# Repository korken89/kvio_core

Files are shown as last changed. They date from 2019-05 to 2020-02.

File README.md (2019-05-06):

# KVision Core - Visual Inertial Core

KVision core is an FPGA based Visual Inertial Odometry accelerator.

More info to come.

---

## Contributors

List of contributors in alphabetical order:

* Emil Fresk ([@korken89](https://github.com/korken89))

---

## License

The hardware is OSHW using the Cern-OHL license.

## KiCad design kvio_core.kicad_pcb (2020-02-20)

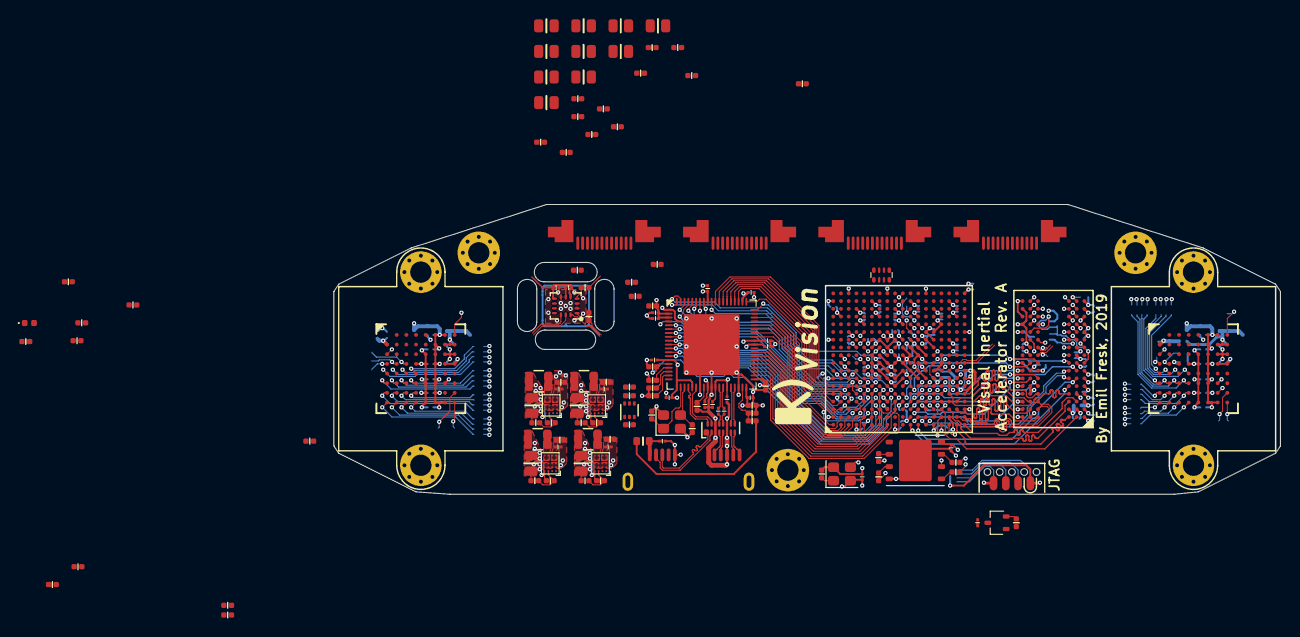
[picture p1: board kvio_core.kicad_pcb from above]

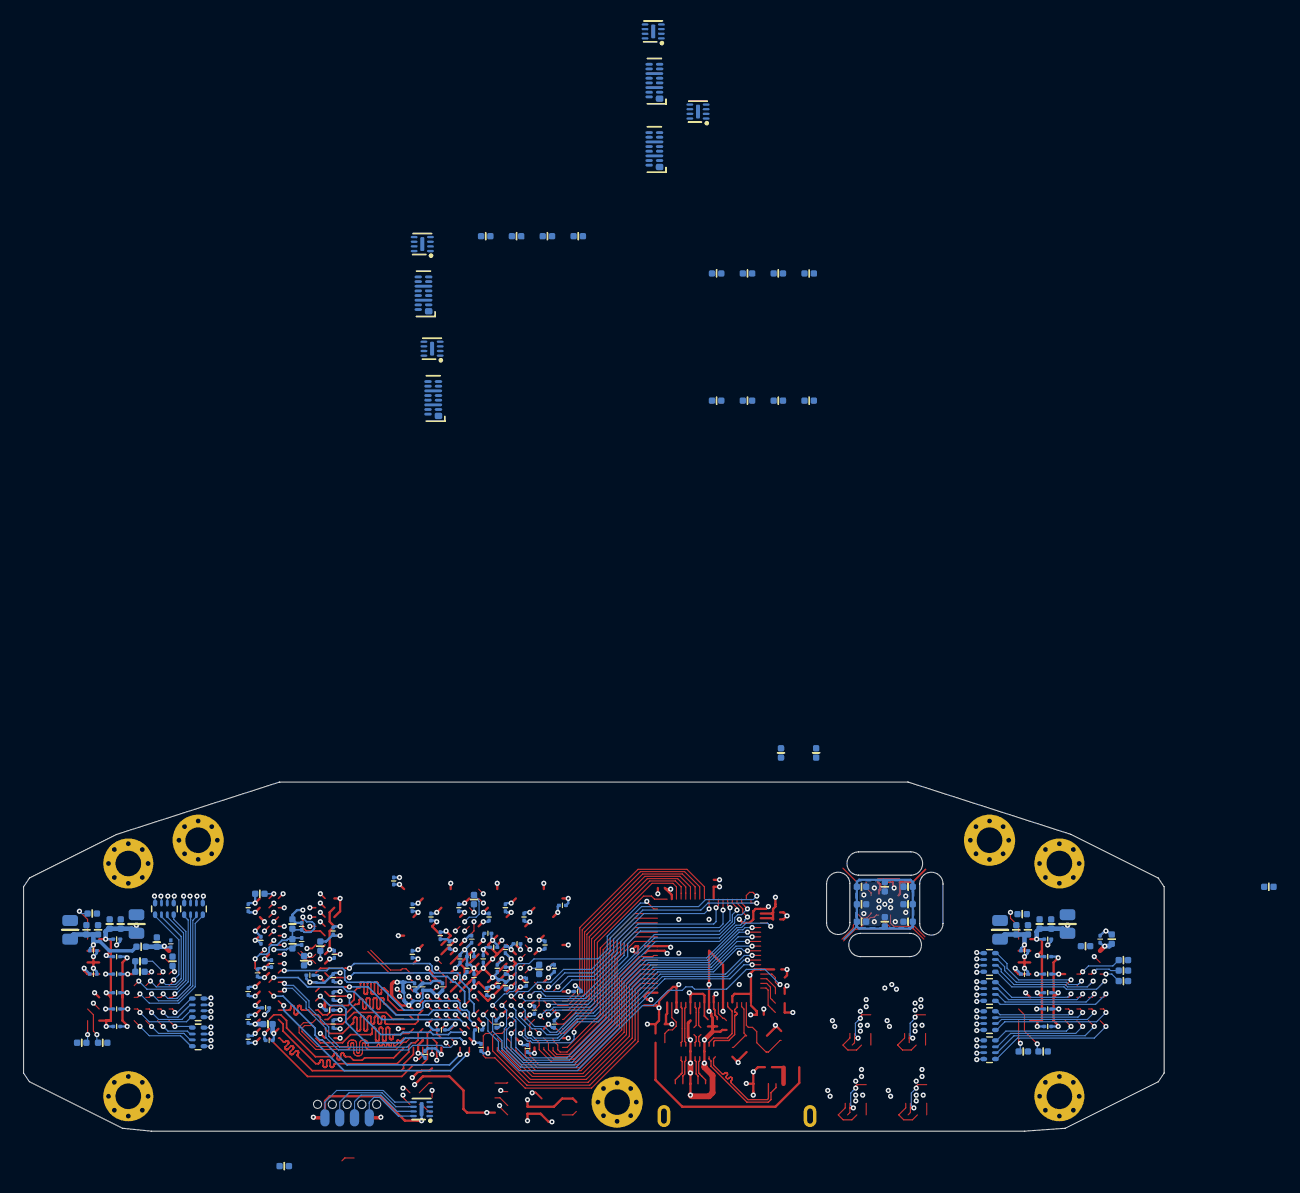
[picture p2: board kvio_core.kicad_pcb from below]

Board: 6 copper layers, 98.0 x 30.0 mm, 287 parts (154 on the bottom side), 316 nets.

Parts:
C101, C215, C216, C220, C221, C223, C224, C226, C227, C229, C230, C231, C232, C233, C234, C235, C236, C237, C240, C241, C243, C244, C245, C248, C249, C251, C252, C253, C254, C255, C261, C262, C263, C264, C265, C266, C267, C268, C269, C270, C272, C275, C278, C281, C284, C285, C301, C302, C1105, C1106, C1110, C1111, C1112, C1113, C1114, C1115, C1116, C1201, C1202, C1204, C1206, C1207, C1208, C1209, C1210, C1211, C1212, C1213, C1214, C1215, C1216, C1217, C1218, C1219, C1220, C1221, C1222, C1301, C1302, C1303, C1306, C1308, C1309, C1310, C1313, C1314, C1315, C1316, C1317, C1318, C1320, C1321, C1405, C1406, C1410, C1411, C1412, C1413, C1414, C1415, C1416: 0.1u; C_0201
C201, C202, C203, C204, C207, C208, C209, C214, C238, C239, C273, C276, C279, C282, C1101, C1104, C1401, C1404: 47u; C_0805
C205, C206, C210, C211, C212, C213, C217, C218, C219, C225, C228, C246, C247, C401, C801, C901, C1001, C1102, C1103, C1107, C1108, C1109, C1203, C1205, C1305, C1307, C1319, C1402, C1403, C1407, C1408, C1409: 4.7u; C_0402
C271, C274, C277, C280: 10u; C_0402
C1311, C1312: 18p; C_0402
D301: GREEN; LED_0402_1005Metric
FB201, FB401, FB801, FB901, FB1001, FB1101, FB1201, FB1401: Ferrite_Bead_Small; R_0402
FB1301: BLM18KG102SH1D; R_0603
H101, H102, H103: MountingHole_Pad; MountingHole_2.2mm_M2_Pad_Via
J401, J801, J901, J1001: 12-pin_FFC_(SFV12R); SFV12R
J1301: USB3_B_Micro; AMPHENOL-GSB343K33HR
L201, L202, L203, L204: 0.47uH; L_2025Metric
LH1101, LH1401: lens_holder; m12_20mm
Q1201: NTZD3155C; SOT-563
R101, R1101, R1102, R1103, R1104, R1302, R1303, R1306, R1401, R1402, R1403, R1404: 10k; R_0402
R201, R202, R203, R204, R205, R206, R207, R208: 0; R_0402
R301, R304, R311, R312, R313, R314, R401, R403, R801, R802, R901, R902, R1001, R1002, R1204, R1206, R1213, R1214, R1215, R1216, R1217: 100; R_0402
R302, R303, R1304, R1305: 470; R_0402
R307, R315, R316, R1205, R1207, R1208, R1210, R1307: 4.7k; R_0402
R308, R310, R1201, R1202: 1k; R_0402
R701, R702, R1105, R1106, R1301: 1.6k; R_0402
R1203: 240; R_0402
R1209, R1211, R1212, R1218, R1219, R1220, R1221, R1222: 180; R_0402
RN101, RN1101, RN1102, RN1103, RN1104, RN1401, RN1402, RN1403, RN1404: 22; R_Array_Convex_4x0402
U101: xc7a100t-csg324; CSG324_Artix7_100T
U102: 100 MHz; Crystal_SMD_2520-4Pin_2.5x2.0mm
U201, U202, U203, U204: FAN53541; WLCSP-20_1.96x1.56mm_Layout4x5_P0.4mm
U301: MX25L6433F; WSON-8-1EP_6x5mm_P1.27mm_EP3.4x4.3mm
U302: MAX809; SOT-323
U303, U402, U801, U901, U1001: IP4254CZ8-4-TTL; UDFN-8-1EP_1.7x1.35mm_P0.4mm_EP0.4x1.2mm
U304: SOICbite_JTAG; SOICbiteSmall
U401, U802, U902, U1002, U1302: EMI8143; XDFN-16_1.35x3.5mm
U1101, U1401: AR0135CS
U1201: MT41J128M16JT-125:K; BGA-96_8.0x14.0mm_DDR16
U1202: ASM330LHH; LGA-14-2.5x3
U1301: FT601Q; QFN-76-1EP_9x9mm_P0.4mm_EP5.8x6.3mm
Y1301: Crystal_GND24_Small; Crystal_SMD_2520-4Pin_2.5x2.0mm

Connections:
+1V0: C209.1, C214.1, C219.1, C225.1, C231.1, C237.1, C239.1, C245.1, C253.1, C255.1, C261.1, C263.1, C266.1, C267.1, C268.1, C269.1, C270.1, C282.1, L204.2, R207.1, U101.F8, U101.F10, U101.G7, U101.G9, U101.G11, U101.H8, U101.J7, U101.J11, U101.K8, U101.L7, U101.L11, U101.M8, U101.M10, U101.N7, U101.N9, U101.N11, U204.A4
+1V5: C201.1, C205.1, C210.1, C215.1, C220.1, C226.1, C232.1, C240.1, C248.1, C279.1, L203.2, R205.1, U101.K4, U101.N3, U101.P6, U101.T2, U101.U5, U101.V8, U203.A4
+1V8: C203.1, C207.1, C212.1, C217.1, C223.1, C229.1, C235.1, C238.1, C243.1, C246.1, C247.1, C251.1, C254.1, C262.1, C264.1, C265.1, C276.1, C1101.1, C1102.1, C1103.1, C1105.1, C1106.1, C1110.1, C1111.1, C1115.1, C1116.1, C1401.1, C1402.1, C1403.1, C1405.1, C1406.1, C1410.1, C1411.1, C1415.1, C1416.1, FB201.2, L202.2, R203.1, R701.2, R702.2, R1105.2, R1106.2, U101.A17, U101.C13, U101.D16, U101.E8, U101.F12, U101.G15, U101.H12, U101.H18, U101.K12, U101.K14, U101.M12, U202.A4, U1101.A6, U1101.A7, U1101.B6, U1101.C6, U1101.D6, U1101.E6, U1101.F6, U1101.G6, U1101.H6, U1101.H7, U1401.A6, U1401.A7, U1401.B6, U1401.C6, U1401.D6, U1401.E6, U1401.F6, U1401.G6, U1401.H6, U1401.H7
+3V3: C101.1, C202.1, C204.1, C206.1, C208.1, C211.1, C213.1, C216.1, C218.1, C221.1, C224.1, C227.1, C228.1, C230.1, C233.1, C234.1, C236.1, C241.1, C244.1, C249.1, C252.1, C273.1, C284.1, C301.2, C302.2, C1305.1, C1306.1, C1308.1, C1309.1, C1313.1, C1314.1, C1316.1, C1317.1, FB1201.2, L201.2, R101.1, R201.1, R302.2, R307.1, R308.1, R315.1, R316.1, R1302.1, U101.A7, U101.B10, U101.C3, U101.D6, U101.F2, U101.G5, U101.J1, U101.L17, U101.N13, U101.P8, U101.P12, U101.P16, U101.R9, U101.T12, U101.U15, U101.V18, U102.4, U201.A4, U301.8, U302.3, U1301.14, U1301.20, U1301.24, U1301.28, U1301.38, U1301.49, U1301.59, U1301.68
/CAM0_CLK: RN101.8, U1401.C1
/CAM0_CLK_P: RN101.1, U101.F18
/CAM0_D0: RN1402.8, U101.B14
/CAM0_D1: RN1402.7, U101.B12
/CAM0_D2: RN1402.6, U101.B11
/CAM0_D3: RN1402.5, U101.A11
/CAM0_D4: RN1403.8, U101.F13
/CAM0_D5: RN1403.7, U101.F14
/CAM0_D6: RN1403.6, U101.D12
/CAM0_D7: RN1403.5, U101.D13
/CAM0_D8: RN1404.8, U101.B16
/CAM0_D9: RN1404.7, U101.B17
/CAM0_D10: RN1404.6, U101.A15
/CAM0_D11: RN1404.5, U101.A16
/CAM0_FLASH: RN1401.1, U101.A18
/CAM0_FV: RN1401.3, U101.A13
/CAM0_LV: RN1401.4, U101.A14
/CAM0_PIXCLK: RN1401.2, U101.D15
/CAM0_RESET: R1404.1, U101.C12, U1401.H8
/CAM0_SCLK: R702.1, U101.E16, U1401.D2
/CAM0_SDATA: R701.1, U101.E15, U1401.D3
/CAM0_TRIGGER: RN101.7, U1401.G7
/CAM0_TRIGGER_P: RN101.2, U101.B18
/CAM1_CLK: RN101.6, U1101.C1
/CAM1_CLK_P: RN101.3, U101.G18
/CAM1_D0: RN1102.8, U101.H16
/CAM1_D1: RN1102.7, U101.G16
/CAM1_D2: RN1102.6, U101.F15
/CAM1_D3: RN1102.5, U101.F16
/CAM1_D4: RN1103.8, U101.H14
/CAM1_D5: RN1103.7, U101.G14
/CAM1_D6: RN1103.6, U101.E17
/CAM1_D7: RN1103.5, U101.D17
/CAM1_D8: RN1104.8, U101.K13
/CAM1_D9: RN1104.7, U101.J13
/CAM1_D10: RN1104.6, U101.H17
/CAM1_D11: RN1104.5, U101.G17
/CAM1_FLASH: RN1101.1, U101.C17
/CAM1_FV: RN1101.3, U101.J14
/CAM1_LV: RN1101.4, U101.H15
/CAM1_PIXCLK: RN1101.2, U101.C15
/CAM1_RESET: R1101.1, U101.B13, U1101.H8
/CAM1_SCLK: R1106.1, U101.D18, U1101.D2
/CAM1_SDATA: R1105.1, U101.E18, U1101.D3
/CAM1_TRIGGER: RN101.5, U1101.G7
/CAM1_TRIGGER_P: RN101.4, U101.C16
/Camera 1/5V_CAM: C401.1, FB401.1, J401.12
/Camera 1/CLK_N: R403.2, U401.12
/Camera 1/CLK_P: R403.1, U401.13
/Camera 1/CLK_P_N: J401.5, U401.5
/Camera 1/CLK_P_P: J401.6, U401.4
/Camera 1/D1_N: R401.2, U401.9
/Camera 1/D1_P: R401.1, U401.10
/Camera 1/D1_P_N: J401.2, U401.8
/Camera 1/D1_P_P: J401.3, U401.7
/Camera 1/IO1_P: J401.8, U402.8
/Camera 1/IO2_P: J401.9, U402.7
/Camera 1/SCL_P: J401.11, U402.5
/Camera 1/SDA_P: J401.10, U402.6
/Camera 2/5V_CAM: C801.1, FB801.1, J801.12
/Camera 2/CLK_N: R802.2, U802.12
/Camera 2/CLK_P: R802.1, U802.13
/Camera 2/CLK_P_N: J801.5, U802.5
/Camera 2/CLK_P_P: J801.6, U802.4
/Camera 2/D1_N: R801.2, U802.9
/Camera 2/D1_P: R801.1, U802.10
/Camera 2/D1_P_N: J801.2, U802.8
/Camera 2/D1_P_P: J801.3, U802.7
/Camera 2/IO1_P: J801.8, U801.8
/Camera 2/IO2_P: J801.9, U801.7
/Camera 2/SCL_P: J801.11, U801.5
/Camera 2/SDA_P: J801.10, U801.6
/Camera 3/5V_CAM: C901.1, FB901.1, J901.12
/Camera 3/CLK_N: R902.2, U902.12
/Camera 3/CLK_P: R902.1, U902.13
/Camera 3/CLK_P_N: J901.5, U902.5
/Camera 3/CLK_P_P: J901.6, U902.4
/Camera 3/D1_N: R901.2, U902.9
/Camera 3/D1_P: R901.1, U902.10
/Camera 3/D1_P_N: J901.2, U902.8
/Camera 3/D1_P_P: J901.3, U902.7
/Camera 3/IO1_P: J901.8, U901.8
/Camera 3/IO2_P: J901.9, U901.7
/Camera 3/SCL_P: J901.11, U901.5
/Camera 3/SDA_P: J901.10, U901.6
/Camera 4/5V_CAM: C1001.1, FB1001.1, J1001.12
/Camera 4/CLK_N: R1002.2, U1002.12
/Camera 4/CLK_P: R1002.1, U1002.13
/Camera 4/CLK_P_N: J1001.5, U1002.5
/Camera 4/CLK_P_P: J1001.6, U1002.4
/Camera 4/D1_N: R1001.2, U1002.9
/Camera 4/D1_P: R1001.1, U1002.10
/Camera 4/D1_P_N: J1001.2, U1002.8
/Camera 4/D1_P_P: J1001.3, U1002.7
/Camera 4/IO1_P: J1001.8, U1001.8
/Camera 4/IO2_P: J1001.9, U1001.7
/Camera 4/SCL_P: J1001.11, U1001.5
/Camera 4/SDA_P: J1001.10, U1001.6
/Config/CFG_CLK: R301.1, R304.1, U301.6
/Config/CFG_CS: R307.2, U101.L13, U301.1
/Config/CFG_D0: R311.1, U101.K17
/Config/CFG_D1: R312.1, U101.K18
/Config/CFG_D2: R313.1, R316.2, U101.L14
/Config/CFG_D3: R314.1, R315.2, U101.M14
/Config/CFG_DONE: R302.1, R303.2, U101.P10
/Config/CFG_INIT_B: R310.1, U101.P7, U101.P9
/Config/CFG_PUDC: R308.2, U101.L15
/Config/SYSTEM_RESET: R310.2, U302.2
/Config/TCK: U101.E10, U303.3
/Config/TCK_P: U303.6, U304.7
/Config/TDI: U101.E11, U303.4
/Config/TDI_P: U303.5, U304.8
/Config/TDO: U101.E13, U303.2
/Config/TDO_P: U303.7, U304.6
/Config/TMS: U101.E12, U303.1
/Config/TMS_P: U303.8, U304.5
/DDR Memory/A0: U101.U6, U1201.N3
/DDR Memory/A1: U101.R6, U1201.P7
/DDR Memory/A2: U101.V7, U1201.P3
/DDR Memory/A3: U101.V6, U1201.N2
/DDR Memory/A4: U101.T8, U1201.P8
/DDR Memory/A5: U101.P5, U1201.P2
/DDR Memory/A6: U101.R8, U1201.R8
/DDR Memory/A7: U101.N5, U1201.R2
/DDR Memory/A8: U101.R7, U1201.T8
/DDR Memory/A9: U101.N6, U1201.R3
/DDR Memory/A10: U101.P4, U1201.L7
/DDR Memory/A11: U101.N4, U1201.R7
/DDR Memory/A12: U101.U7, U1201.N7
/DDR Memory/A13: U101.M6, U1201.T3
/DDR Memory/BA0: U101.R5, U1201.M2
/DDR Memory/BA1: U101.U8, U1201.N8
/DDR Memory/BA2: U101.P3, U1201.M3
/DDR Memory/CAS_N: U101.R2, U1201.K3
/DDR Memory/CK_E: U101.T6, U1201.K9
/DDR Memory/CK_N: R1204.2, U101.V9, U1201.K7
/DDR Memory/CK_P: R1204.1, U101.U9, U1201.J7
/DDR Memory/CS_N: U101.P2, U1201.L2
/DDR Memory/DDR3_VDD: C1201.1, C1203.1, C1204.1, C1206.1, C1207.2, C1208.1, C1210.1, C1211.2, C1212.1, C1213.2, C1214.1, C1215.2, C1216.1, C1217.2, C1218.1, C1219.2, C1220.1, C1221.2, R1201.1, U1201.A1, U1201.A8, U1201.B2, U1201.C1, U1201.C9, U1201.D2, U1201.D9, U1201.E9, U1201.F1, U1201.G7, U1201.H2, U1201.H9, U1201.K2, U1201.K8, U1201.N1, U1201.N9, U1201.R1, U1201.R9
/DDR Memory/DQ0: U101.L1, U1201.E3
/DDR Memory/DQ1: U101.L4, U1201.F7
/DDR Memory/DQ2: U101.M1, U1201.F2
/DDR Memory/DQ3: U101.M3, U1201.F8
/DDR Memory/DQ4: U101.K3, U1201.H3
/DDR Memory/DQ5: U101.L6, U1201.H8
/DDR Memory/DQ6: U101.L3, U1201.G2
/DDR Memory/DQ7: U101.K5, U1201.H7
/DDR Memory/DQ8: U101.V5, U1201.D7
/DDR Memory/DQ9: U101.T3, U1201.C3
/DDR Memory/DQ10: U101.U4, U1201.C8
/DDR Memory/DQ11: U101.V1, U1201.C2
/DDR Memory/DQ12: U101.U3, U1201.A7
/DDR Memory/DQ13: U101.R3, U1201.A2
/DDR Memory/DQ14: U101.T5, U1201.B8
/DDR Memory/DQ15: U101.U1, U1201.A3
/DDR Memory/LDM: U101.M2, U1201.E7
/DDR Memory/LDQS_N: U101.N1, U1201.G3
/DDR Memory/LDQS_P: U101.N2, U1201.F3
/DDR Memory/ODT: U101.R1, U1201.K1
/DDR Memory/RAS_N: U101.T1, U1201.J3
/DDR Memory/RESET_N: R1205.1, U101.K6, U1201.T2
/DDR Memory/UDM: U101.V4, U1201.D3
/DDR Memory/UDQS_N: U101.V2, U1201.B7
/DDR Memory/UDQS_P: U101.U2, U1201.C7
/DDR Memory/VREF: C1201.2, C1202.1, R1201.2, R1202.1, U1201.H1, U1201.M8
/DDR Memory/WE_N: U101.M4, U1201.L3
/DDR Memory/ZQ: R1203.1, U1201.L8
/IMU_CS: R1215.1, U101.B9
/IMU_HEATER: R1206.2, U101.C11
/IMU_INT: R1210.1, R1217.1, U101.A8
/IMU_SCK: R1214.1, U101.C9
/IMU_SDI: R1213.1, U101.D9
/IMU_SDO: R1216.1, U101.B8
/Parallel camera/D0_P: RN1402.1, U1401.H1
/Parallel camera/D1_P: RN1402.2, U1401.H2
/Parallel camera/D2_P: RN1402.3, U1401.H3
/Parallel camera/D3_P: RN1402.4, U1401.H4
/Parallel camera/D4_P: RN1403.1, U1401.G1
/Parallel camera/D5_P: RN1403.2, U1401.G2
/Parallel camera/D6_P: RN1403.3, U1401.G3
/Parallel camera/D7_P: RN1403.4, U1401.G4
/Parallel camera/D8_P: RN1404.1, U1401.F1
/Parallel camera/D9_P: RN1404.2, U1401.F2
/Parallel camera/D10_P: RN1404.3, U1401.F3
/Parallel camera/D11_P: RN1404.4, U1401.F4
/Parallel camera/FLASH_P: RN1401.8, U1401.E4
/Parallel camera/FV_P: RN1401.6, U1401.E2
/Parallel camera/LV_P: RN1401.5, U1401.E1
/Parallel camera/PIXCLK_P: RN1401.7, U1401.E3
/Parallel camera/SADDR: R1402.1, U1401.D1
/Parallel camera/STANDBY: R1401.1, U1401.A8
/Parallel camera/VPLL: C1407.1, C1412.1, FB1401.1, U1401.B1
/Parallel camera/~OE: R1403.1, U1401.G8
/Power/SW10: L204.1, U204.D3, U204.D4, U204.E3, U204.E4
/Power/SW13: L203.1, U203.D3, U203.D4, U203.E3, U203.E4
/Power/SW18: L202.1, U202.D3, U202.D4, U202.E3, U202.E4
/Power/SW33: L201.1, U201.D3, U201.D4, U201.E3, U201.E4
/Power/VCCADC: C285.1, FB201.1, U101.H10
/Power/VIN: C271.1, C272.1, C274.1, C275.1, C277.1, C278.1, C280.1, C281.1, U201.D1, U201.D2, U201.E1, U201.E2, U202.D1, U202.D2, U202.E1, U202.E2, U203.D1, U203.D2, U203.E1, U203.E2, U204.D1, U204.D2, U204.E1, U204.E2
/Sensors/HEATER_SIG: Q1201.5, R1206.1, R1207.1
/Sensors/IMU_CS_P: R1215.2, U1202.12
/Sensors/IMU_HEATER: Q1201.6, R1209.1, R1211.1, R1212.1, R1218.1, R1219.1, R1220.1, R1221.1, R1222.1
/Sensors/IMU_INT_P: R1217.2, U1202.4
/Sensors/IMU_PWR: C1205.1, C1209.1, C1222.1, FB1201.1, U1202.5, U1202.8
/Sensors/IMU_SCK_P: R1214.2, U1202.13
/Sensors/IMU_SDI_P: R1213.2, U1202.14
/Sensors/IMU_SDO_P: R1216.2, U1202.1
/Sensors/V_HEATER: Q1201.1, R1208.1
/USB3 Interface/BE_0: U101.C5, U1301.4
/USB3 Interface/BE_1: U101.E6, U1301.5
/USB3 Interface/BE_2: U101.E5, U1301.6
/USB3 Interface/BE_3: U101.D4, U1301.7
/USB3 Interface/CLK: U101.E3, U1301.58
/USB3 Interface/D2_N: J1301.2, U1302.2
/USB3 Interface/D2_P: J1301.3, U1302.1
/USB3 Interface/DATA_0: U101.J4, U1301.40
/USB3 Interface/DATA_1: U101.G3, U1301.41
/USB3 Interface/DATA_2: U101.H1, U1301.42
/USB3 Interface/DATA_3: U101.H2, U1301.43
/USB3 Interface/DATA_4: U101.G1, U1301.44
/USB3 Interface/DATA_5: U101.G2, U1301.45
/USB3 Interface/DATA_6: U101.F1, U1301.46
/USB3 Interface/DATA_7: U101.E1, U1301.47
/USB3 Interface/DATA_8: U101.E2, U1301.50
/USB3 Interface/DATA_9: U101.D2, U1301.51
/USB3 Interface/DATA_10: U101.C1, U1301.52
/USB3 Interface/DATA_11: U101.C2, U1301.53
/USB3 Interface/DATA_12: U101.B1, U1301.54
/USB3 Interface/DATA_13: U101.B2, U1301.55
/USB3 Interface/DATA_14: U101.A1, U1301.56
/USB3 Interface/DATA_15: U101.H5, U1301.57
/USB3 Interface/DATA_16: U101.B3, U1301.60
/USB3 Interface/DATA_17: U101.A3, U1301.61
/USB3 Interface/DATA_18: U101.B4, U1301.62
/USB3 Interface/DATA_19: U101.A4, U1301.63
/USB3 Interface/DATA_20: U101.A5, U1301.64
/USB3 Interface/DATA_21: U101.B6, U1301.65
/USB3 Interface/DATA_22: U101.A6, U1301.66
/USB3 Interface/DATA_23: U101.B7, U1301.67
/USB3 Interface/DATA_24: U101.D8, U1301.69
/USB3 Interface/DATA_25: U101.D7, U1301.70
/USB3 Interface/DATA_26: U101.D5, U1301.71
/USB3 Interface/DATA_27: U101.E7, U1301.72
/USB3 Interface/DATA_28: U101.C4, U1301.73
/USB3 Interface/DATA_29: U101.C6, U1301.74
/USB3 Interface/DATA_30: U101.F6, U1301.75
/USB3 Interface/DATA_31: U101.C7, U1301.76
/USB3 Interface/D_N: U1301.25, U1302.15
/USB3 Interface/D_P: U1301.23, U1302.16
/USB3 Interface/GLCLK_100MHZ: U101.D3, U102.3
/USB3 Interface/OE_N: U101.H4, U1301.13
/USB3 Interface/RD_N: U101.G6, U1301.12
/USB3 Interface/RESET: R1303.2, U101.J5, U1301.15
/USB3 Interface/RREF: R1301.1, U1301.27
/USB3 Interface/RX2_N: J1301.9, U1302.7
/USB3 Interface/RX2_P: J1301.10, U1302.8
/USB3 Interface/RXF_N: U101.G4, U1301.9
/USB3 Interface/RX_N: U1301.34, U1302.10
/USB3 Interface/RX_P: U1301.35, U1302.9
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

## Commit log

2019-06-30 More added
    [camera.sch, config.sch, ddr.sch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]
2019-07-06 More stuff
    [camera.sch, ddr.sch, kvio_core.kicad_pcb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]
2019-07-07 DDR3 routed, length matching left
    [camera.sch, config.sch, ddr.sch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]
2019-07-08 Before length matching
    [kvio_core.kicad_pcb]
2019-07-08 Data groups length matched
    [camera.sch, config.sch, ddr.sch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]
2019-07-08 Length matching done (except CK, needs final layers)
    [kvio_core.kicad_pcb]
2019-07-08 Cleaning up length tuning
    [kvio_core.kicad_pcb]
2019-07-11 Fixing for adding pad lengths
    [kvio_core.kicad_pcb]
2019-07-11 Added pad-to-die length file
    [p2d_length_100t.csv]
2019-07-11 New length matching
    [kvio_core.kicad_pcb, kvio_core.sch]
2019-07-11 Now with DDR3 1.5 mm closer
    [kvio_core.kicad_pcb]
2019-07-12 Updates to length matching and added GND plane for DDR3
    [kvio_core.kicad_pcb]
2019-07-19 More design
    [camera.sch, config.sch, ddr.sch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]
2019-07-25 More additions, DDR3 caps placed
    [camera.sch, config.sch, ddr.sch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]
2019-07-25 Fixing with DDR3, needs retuning
    [camera.sch, config.sch, ddr.sch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]
2019-07-30 More layout and design
    [camera.sch, config.sch, ddr.sch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]
2019-07-31 Added 2 cameras via parallel interface
    [camera.sch, config.sch, ddr.sch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]
2019-08-01 USB3 FIFO layout done, some testing with camera connectors
    [camera.sch, config.sch, kvio_core.kicad_pcb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]
2019-08-02 Added IMU
    [camera.sch, kvio_core.kicad_pcb, kvio_core.sch]
2019-08-03 Added IMU + heater, fixed USB3 FIFO lines
    [camera.sch, config.sch, ddr.sch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]
2019-08-05 More layout
    [camera.sch, kvio_core.kicad_pcb, kvio_core.sch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]
2019-08-06 More work
    [camera.sch, config.sch, ddr.sch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]
2019-08-07 Added signal for global clock
    [config.sch, kvio_core.kicad_pcb, parallel_camera.sch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]
